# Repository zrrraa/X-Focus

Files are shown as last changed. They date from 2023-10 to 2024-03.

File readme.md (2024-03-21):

# X-Focus 智能桌面伴侣

一个可检测使用者学习和工作情况以及环境噪声的桌面伴侣，在APP内可查看监督报告。

<center class = 'img' >
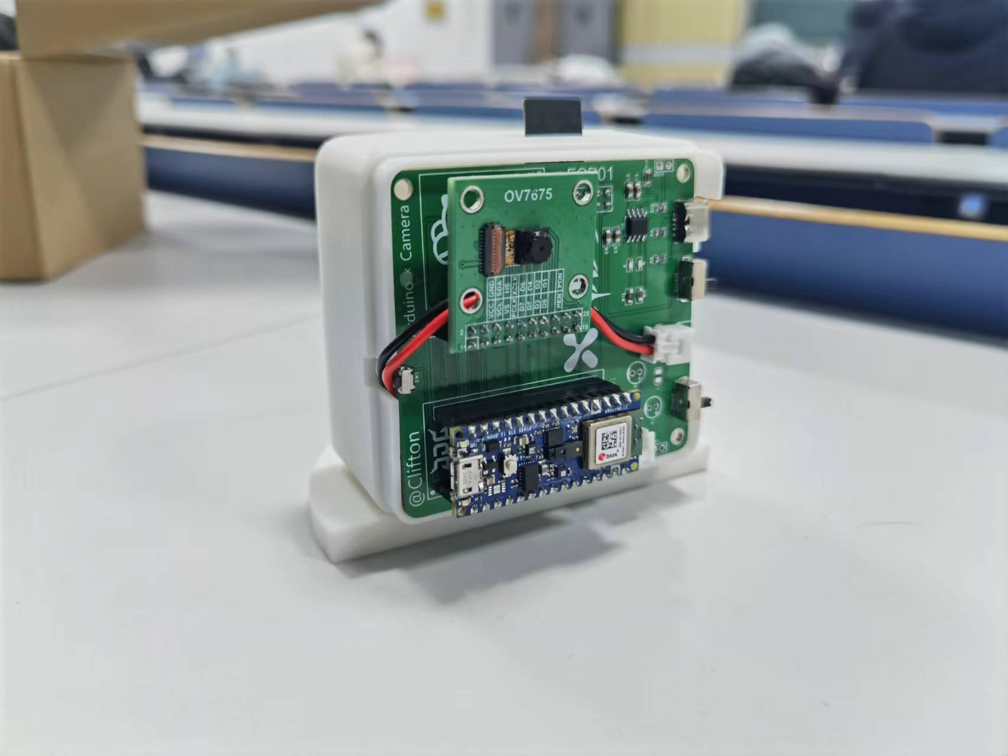
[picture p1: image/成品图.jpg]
X-Focus

</center>

随着媒体技术的发展和互联网时代的革命，洪流般的信息在推动时代进步的同时也无形中降低了人们的耐心阈值。当“专注”成为普遍关注的话题，如何检测专注度便成为了亟待解决的问题。

X-Focus诞生于这样的情境之下，旨在打造一款陪伴用户学习与工作的智能桌面伴侣，助力检验专注度。

## 技术路径

<center class = 'img' >
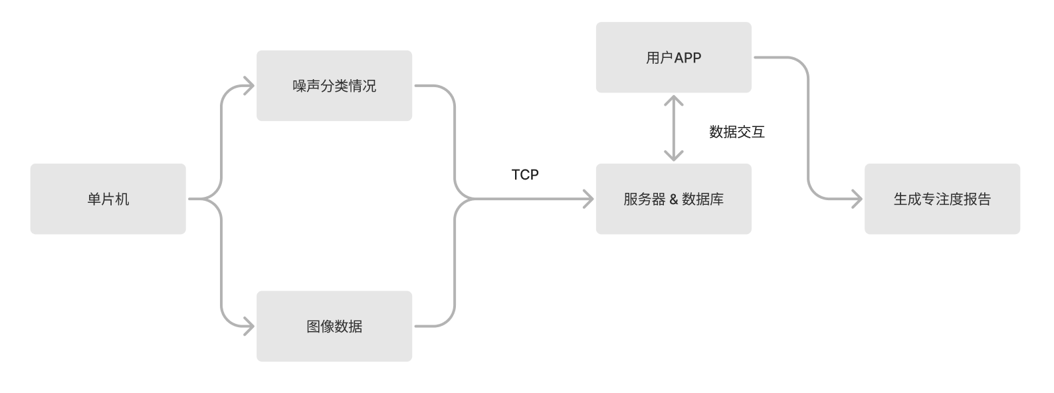
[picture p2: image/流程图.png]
流程图

</center>

硬件部分，X-Focus采用Arduino Nano 33 BLE作为主控，利用ov7675摄像头实时读取用户的工作状态，同时利用MP34DT05实时采集环境噪声。噪声经由存在单片机内部的预训练神经网络模型权重参数直接计算得分类结果，而图像数据则通过esp8266基于TCP发送给服务器，在服务器中通过SVM预测用户当前的工作状态。软件部分，我们基于PYQT5搭建了轻量级的上位机APP，协同后端SQLite数据库进行数据交互，每个用户都可注册自己的账号，查阅独属于自己的专注度报告，实现了一台设备的多人共享，助力X-Focus走进图书馆，办公室等公共场合。

## 功能演示

开机启动X-Focus

https://github.com/zrrraa/X-Focus/assets/105407119/f7af75d5-0d5c-4295-9356-713c125a4616

使用电脑状态检测

https://github.com/zrrraa/X-Focus/assets/105407119/e276f914-b43a-4757-9397-768390018e64

离开状态检测

https://github.com/zrrraa/X-Focus/assets/105407119/6a12a4db-4bc4-4c27-8759-1919a981f59a

读书状态以及使用手机状态检测

https://github.com/zrrraa/X-Focus/assets/105407119/01b09853-e76d-4802-b92e-d4feedbde9a1

用户在每一次学习或工作结束后都可在APP上查看状态报告，并与过去的报告进行对比，分析专注度。

<center class = 'img' >
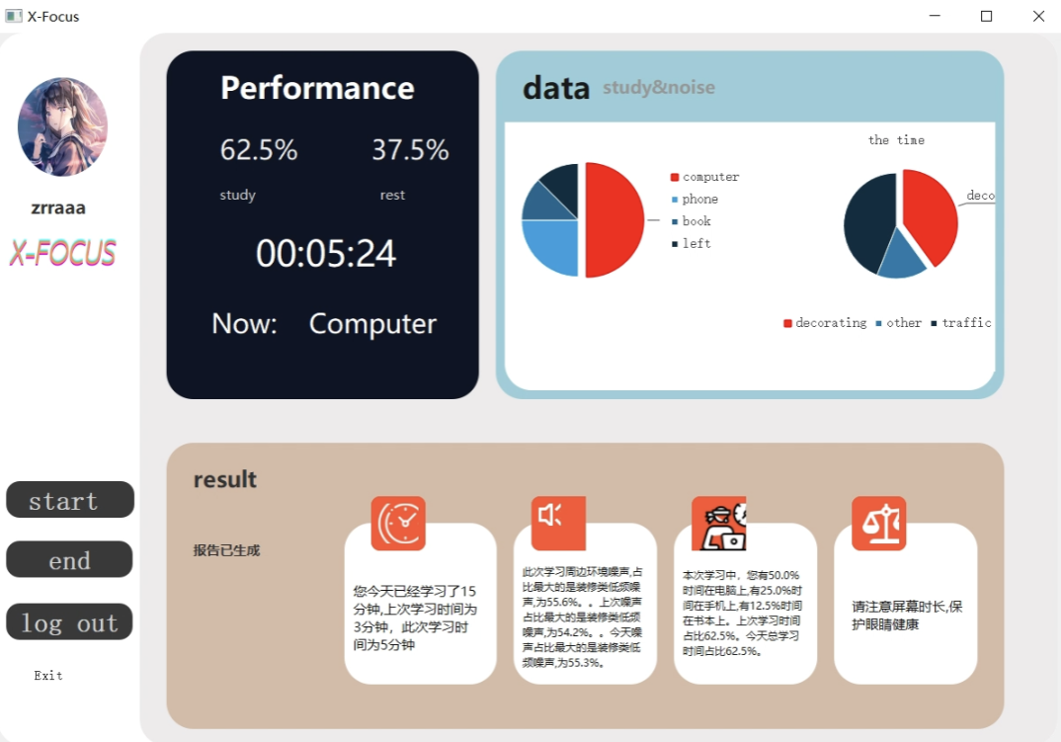
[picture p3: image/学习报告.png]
学习报告

</center>

## 参考资料

[SVMImageClassification](https://github.com/chestnut24/SVMImageClassification "基于SVM的简单机器学习分类，可以使用svm, knn, 朴素贝叶斯，决策树四种机器学习方法进行分类")

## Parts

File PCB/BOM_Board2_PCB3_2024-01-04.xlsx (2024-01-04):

No. | Quantity | Comment | Designator | Footprint | Value | Manufacturer Part | Manufacturer | Supplier Part | Supplier
1 | 3 | B-2100S02P-A110 | +5V,VBAT,VUSB | HDR-TH_2P-P2.54-V-M-1 |  | B-2100S02P-A110 | Ckmtw(灿科盟) | C124375 | LCSC
2 | 1 | 47uF | C1 | CAP-TH_BD5.0-P2.00-D0.8-FD | 47uF | 25YXF47MEFC5X11 | rubycon(红宝石) | C88724 | LCSC
3 | 1 | 100uF | C2 | CAP-TH_BD5.0-P2.00-D0.8-FD | 100uF | KM107M016D11RR0VH2FP0 | CX(承兴) | C43348 | LCSC
4 | 4 | 10u | C3,C4,C5,C6 | C0805 | 10u
5 | 2 | SK12D07VG3 | CHARGE,POWER | 拨动开关_侧 |  | SK12D07VG3 | SHOU HAN(首韩) | C431547 | LCSC
6 | 1 | XH-W-2A | CN1 | CONN-TH_2P-P2.50_DEALON_XH-W-2A |  | XH-W-2A | DEALON(德艺隆) | C5160919 | LCSC
7 | 1 | SS34 | D1 | SMA_L4.3-W2.6-LS5.2-RD |  | SS34 | MDD | C8678 | LCSC
8 | 1 | DS1023-2*4SF11 | ESP01 | HDR-TH_8P-P2.54-V-F-R2-C4-S2.54-1 |  | DS1023-2*4SF11 | CONNFLY | C92271 | LCSC
9 | 1 | LED_0805-G | G | LED_0603
10 | 2 | HDR-F_2.54_1x15P | H1,H2 | HDR-TH_15P-P2.54-V-F-1 |  |  |  | C124408
11 | 1 | HDR-F_2.54_2x10 | H3 | HDR-TH_20P-P2.54-V-R2-C10-S2.54 |  |  |  | C30867
12 | 1 | 47uH | L1 | L0805 | 47uH
13 | 1 | LED_0805-R | LED1 | LED_0603
14 | 1 | LED_0603-R | R | LED_0603
15 | 3 | 0R | R1,R3,R5 | R0805 | 0R
16 | 2 | 10K | R7,R12 | R0805 | 10K
17 | 2 | 6.6k | R8,R9 | R0805 | 6.6k
18 | 1 | 0.25R | R10 | R0805 | 0.25R
19 | 1 | 2K | R11 | R0805 | 2K
20 | 1 | 1.2K | R13 | R0805 | 1.2K
21 | 1 | TS24CA | SW1 | SW-SMD_TS24CA |  | TS24CA | SHOU HAN(首韩) | C393942 | LCSC
22 | 1 | QX2303L50T | U1 | SOT-23-3_L2.9-W1.6-P1.90-LS2.8-BR |  | QX2303L50T | 泉芯 | C219027 | LCSC
23 | 1 | TP4056-42-ESOP8 | U2 | ESOP-8_L4.9-W3.9-P1.27-LS6.0-BL-EP |  | TP4056-42-ESOP8 | TOPPOWER(南京拓微) | C16581 | LCSC
24 | 1 | YTC-TC6-268 | U3 | TYPE-C-SMD_YIYUAN_YTC-TC6-268 |  | YTC-TC6-268 | YIYUAN(怡远) | C5260484 | LCSC

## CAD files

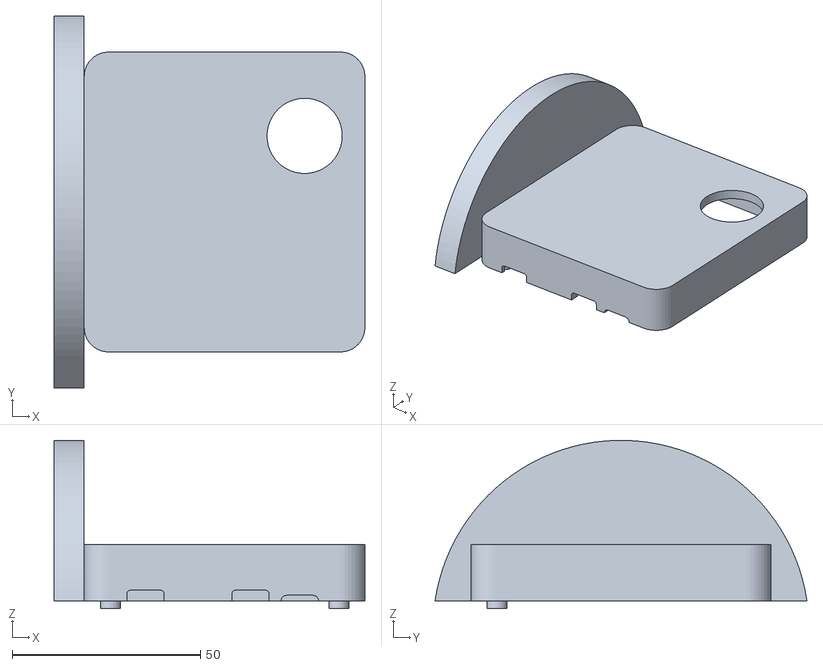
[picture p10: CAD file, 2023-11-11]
3Dmodel/顶部_v3.stl
82.7 x 98.9 x 44.7

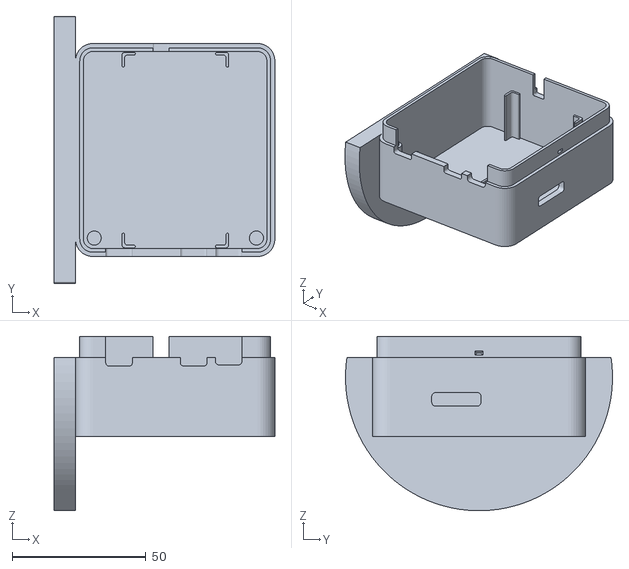
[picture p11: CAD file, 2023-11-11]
3Dmodel/底部_v3.stl
82.7 x 100.0 x 65.3

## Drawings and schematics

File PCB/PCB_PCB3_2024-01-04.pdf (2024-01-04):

@Clifton | Arduino | Camera

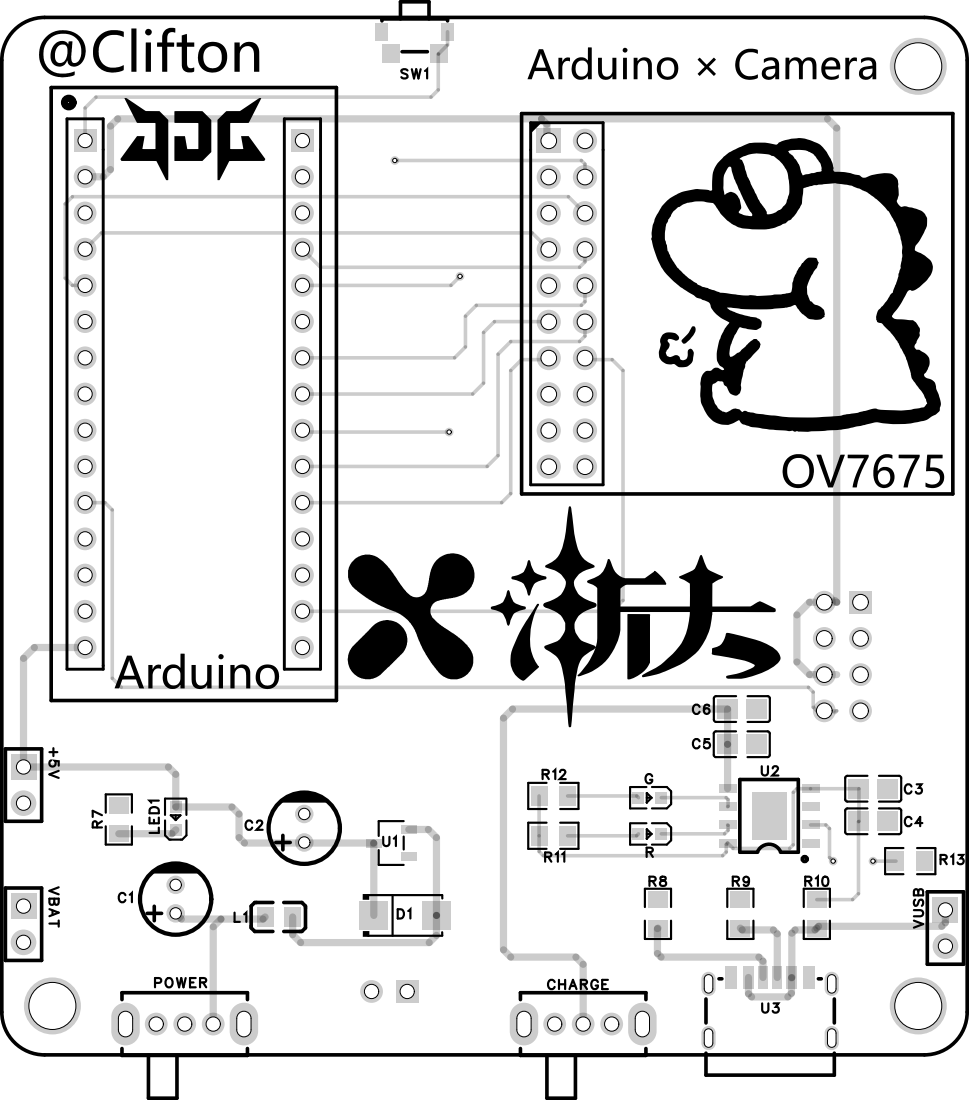
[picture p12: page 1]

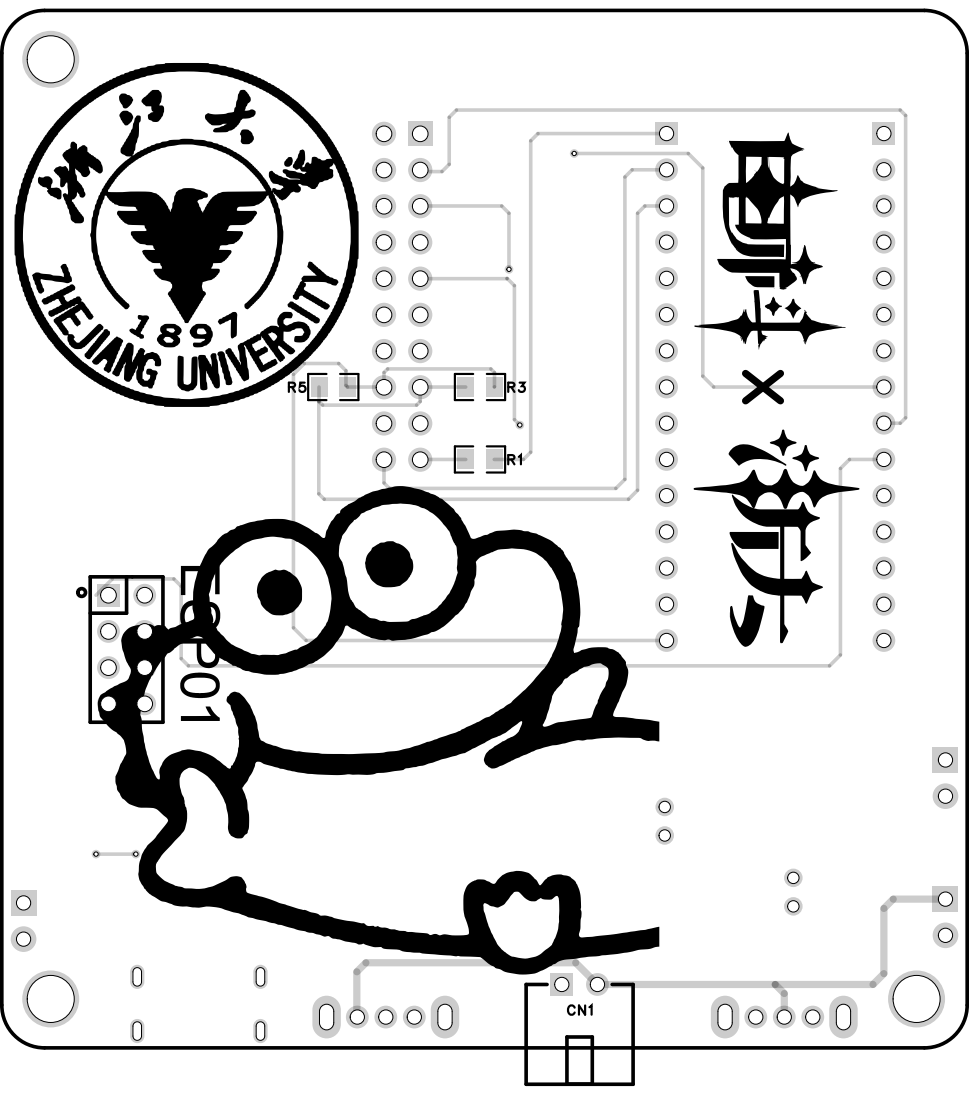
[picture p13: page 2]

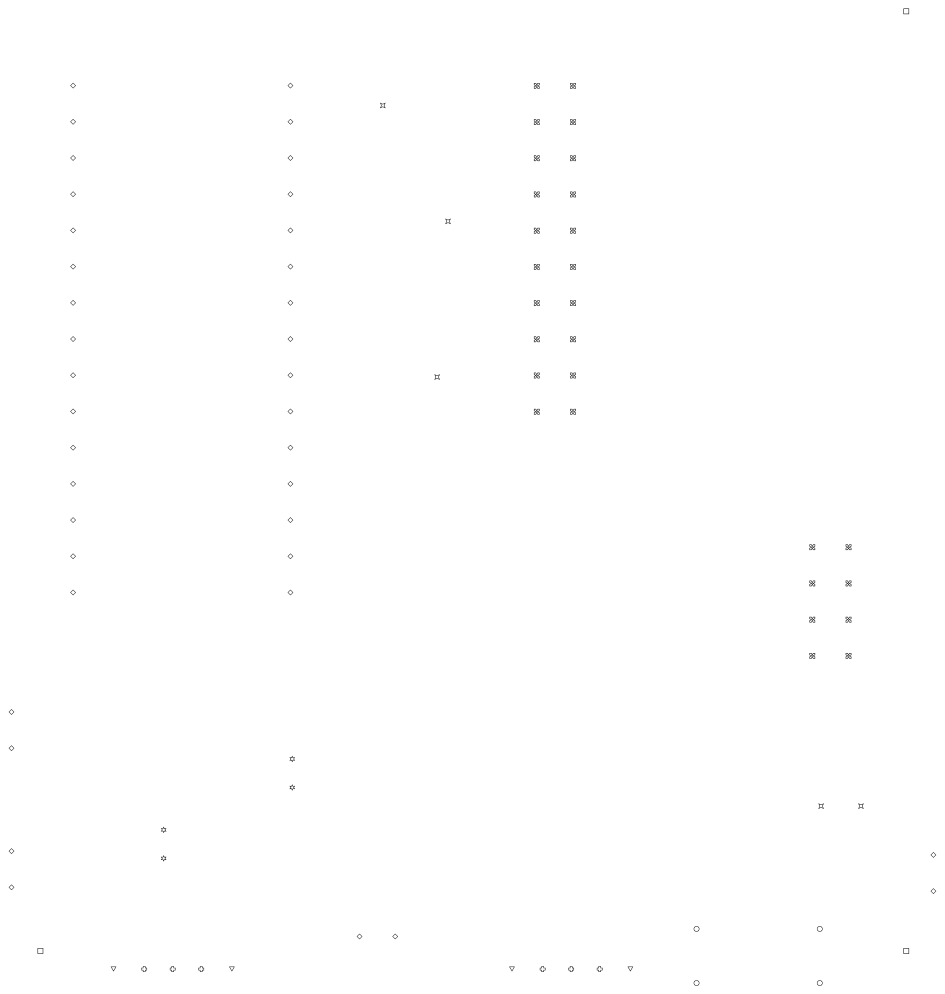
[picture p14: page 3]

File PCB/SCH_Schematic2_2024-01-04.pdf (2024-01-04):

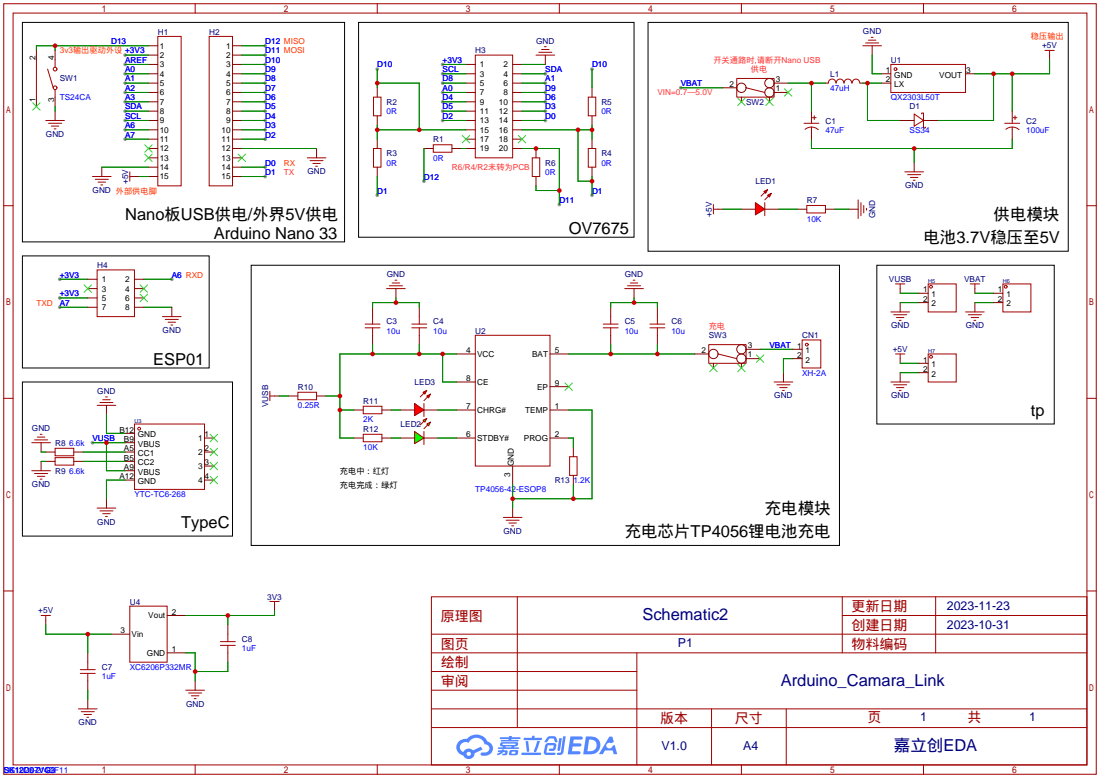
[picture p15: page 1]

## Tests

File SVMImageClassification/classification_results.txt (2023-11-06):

SVMImageClassification/test_photo/output_image_1.png:0
SVMImageClassification/test_photo/output_image_1.png:0
SVMImageClassification/test_photo/output_image_1.png:0
SVMImageClassification/test_photo/output_image_1.png:3
SVMImageClassification/test_photo/output_image_1.png:2
SVMImageClassification/test_photo/output_image_1.png:1
SVMImageClassification/test_photo/output_image_1.png:1
SVMImageClassification/test_photo/output_image_1.png:0
SVMImageClassification/test_photo/output_image_1.png:0
SVMImageClassification/test_photo/output_image_1.png:0
SVMImageClassification/test_photo/output_image_1.png:0
SVMImageClassification/test_photo/output_image_1.png:3
SVMImageClassification/test_photo/output_image_1.png:2
SVMImageClassification/test_photo/output_image_1.png:1
SVMImageClassification/test_photo/output_image_1.png:1
SVMImageClassification/test_photo/output_image_1.png:0
SVMImageClassification/test_photo/output_image_1.png:0
SVMImageClassification/test_photo/output_image_1.png:0
SVMImageClassification/test_photo/output_image_1.png:0
SVMImageClassification/test_photo/output_image_1.png:0
SVMImageClassification/test_photo/output_image_1.png:0
SVMImageClassification/test_photo/output_image_1.png:0
SVMImageClassification/test_photo/output_image_1.png:0
SVMImageClassification/test_photo/output_image_1.png:0
SVMImageClassification/test_photo/output_image_1.png:0
SVMImageClassification/test_photo/output_image_1.png:0

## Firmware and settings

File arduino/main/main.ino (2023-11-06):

#include <TinyMLShield.h>

#include <PDM.h>
#include <voice_detection_inferencing.h>

// wifi_upload, A6 for TX, A7 for RX
UART softSerial1(analogPinToPinName(6), analogPinToPinName(7), NC, NC);



// audio buffers, pointers and selectors
typedef struct {
  int16_t *buffer;
  uint8_t buf_ready;
  uint32_t buf_count;
  uint32_t n_samples;
} inference_t;

static inference_t inference;
static signed short sampleBuffer[2048];
static bool debug_nn = false; // Set this to true to see e.g. features generated from the raw signal

// camera flags
bool commandRecv = false; // flag used for indicating receipt of commands from serial port
bool liveFlag = false; // flag as true to live stream raw camera bytes, set as false to take single images on command
bool captureFlag = true;

// Image buffer
byte image[320 * 240 * 2]; // QVGA: 320x240 x 2 bytes per pixel (RGB565)
long long bytesPerFrame;

// setup
void setup() {
  Serial.begin(115200);
  while (!Serial);
  softSerial1.begin(115200);
  while (!softSerial1);

  // softSerial1.println("softSerial test");
  initializeShield();

  // initialize the microphone
  if (microphone_inference_start(EI_CLASSIFIER_RAW_SAMPLE_COUNT) == false) {
    ei_printf("ERR: Could not allocate audio buffer (size %d), this could be due to the window length of your model\r\n", EI_CLASSIFIER_RAW_SAMPLE_COUNT);
    return;
  }

  // initialize the OV7675 camera
  if (!Camera.begin(QVGA, RGB565, 1, OV7675)) {
    Serial.println("Failed to initialize camera");
    while (1);
  }
  bytesPerFrame = Camera.width() * Camera.height() * Camera.bytesPerPixel();

  if (microphone_inference_start(EI_CLASSIFIER_RAW_SAMPLE_COUNT) == false) {
        ei_printf("ERR: Could not allocate audio buffer (size %d), this could be due to the window length of your model\r\n", EI_CLASSIFIER_RAW_SAMPLE_COUNT);
        return;
    }

  //Serial.println("Welcome to the OV7675 test\n");
  //Serial.println("Available commands:\n");
  //Serial.println("single - take a single image and print out the hexadecimal for each pixel (default)");
  //Serial.println("live - the raw bytes of images will be streamed live over the serial port");
  //Serial.println("capture - when in single mode, initiates an image capture");


  //wifi init
  //Serial.begin(115200);
  // Serial1.begin(115200);
  // delay(3000);
  // Serial.println("wifi STA TCP test begin!");
  // Serial1.println("AT+CIPSTART=\"TCP\",\"192.168.124.7\",8080");
  // Serial.println("AT+CIPSTART=\"TCP\",\"192.168.124.7\",8080,WAITING...");
  // delay(5000);

  // Serial1.println("AT+CIPMODE=1");
  // Serial.println("AT+CIPMODE=1,WAITING...");
  // delay(2000);

  // Serial1.println("AT+CIPSEND");
  // Serial.println("AT+CIPSEND,WAITING...");
  // delay(2000);



  // initialize esp-01

  // softSerial1.listen();
  delay(3000);
  softSerial1.println("AT+CIPSTART=\"TCP\",\"192.168.124.7\",8090");
  delay(5000);

  softSerial1.println("AT+CIPMODE=1");
  delay(2000);

  softSerial1.println("AT+CIPSEND");
  delay(2000);
}

void loop() {
  int i = 0;
  String command;

  bool clicked = readShieldButton();
  if (clicked) {
    if (!liveFlag) {
      if (!captureFlag) {
        captureFlag = true;
      }
    }
  }

  

  // noise classfication and upload
  Serial.println("noise classfication and upload");
  delay(2000);

  bool m = microphone_inference_record();
  if (!m) {
    ei_printf("ERR: Failed to record audio...\n");
    return;
  }
  
  signal_t signal;
  signal.total_length = EI_CLASSIFIER_RAW_SAMPLE_COUNT;
  signal.get_data = &microphone_audio_signal_get_data;
  ei_impulse_result_t result = { 0 };

  EI_IMPULSE_ERROR r = run_classifier(&signal, &result, debug_nn);
  if (r != EI_IMPULSE_OK) {
    ei_printf("ERR: Failed to run classifier (%d)\n", r);
    return;
  }
  //  // print the predictions
  //  ei_printf("Predictions ");
  //  ei_printf("(DSP: %d ms., Classification: %d ms., Anomaly: %d ms.)",
  //            result.timing.dsp, result.timing.classification, result.timing.anomaly);
  //  ei_printf(": \n");
  for (size_t ix = 0; ix < EI_CLASSIFIER_LABEL_COUNT; ix++) {
    ei_printf("%s: %.5f\n", result.classification[ix].label, result.classification[ix].value);
  }
  for (size_t ix = 0; ix < EI_CLASSIFIER_LABEL_COUNT; ix++) {
    softSerial1.print(result.classification[ix].value);

    if (ix != EI_CLASSIFIER_LABEL_COUNT - 1) {
      softSerial1.print(", ");
    }
  }
  softSerial1.print("; ");// ";" to split noise and photo
#if EI_CLASSIFIER_HAS_ANOMALY == 1
  ei_printf("    anomaly score: %.3f\n", result.anomaly);
#endif

  // photo capture and upload
  Serial.println("photo capture and upload");
  if (captureFlag) {
    captureFlag = false;
    Camera.readFrame(image);
    //Serial.println("\nImage data will be printed out in 3 seconds...");
    delay(3000);
    //      for (int i = 0; i < bytesPerFrame - 1; i += 2) {
    //        Serial.print("0x");
    //        Serial.print(image[i+1], HEX);
    //        Serial.print(image[i], HEX);
    //        if (i != bytesPerFrame - 2) {
    //          Serial.print(", ");
    //        }
    //      }
    //      Serial.println();
    Serial.println("uploading photo...");

    //wifi upload
    for (int i = 0; i < bytesPerFrame - 1; i += 2) {
      softSerial1.print("0x");
      softSerial1.print(image[i + 1], HEX);
      softSerial1.print(image[i], HEX);
      if (i != bytesPerFrame - 2) {
        softSerial1.print(", ");
      }
    }
    // "\n" for once upload
    softSerial1.println();
    captureFlag = true;

    //time interval
    delay(5000);//20s一次

  }
}

// noise detection lib
/**
   @brief      PDM buffer full callback
               Get data and call audio thread callback
*/
static void pdm_data_ready_inference_callback(void)
{
  int bytesAvailable = PDM.available();

  // read into the sample buffer
  int bytesRead = PDM.read((char *)&sampleBuffer[0], bytesAvailable);

  if (inference.buf_ready == 0) {
    for (int i = 0; i < bytesRead >> 1; i++) {
      inference.buffer[inference.buf_count++] = sampleBuffer[i];

      if (inference.buf_count >= inference.n_samples) {
        inference.buf_count = 0;
        inference.buf_ready = 1;
        break;
      }
    }
  }
}

/**
   @brief      Init inferencing struct and setup/start PDM

   @param[in]  n_samples  The n samples

   @return     { description_of_the_return_value }
*/
static bool microphone_inference_start(uint32_t n_samples)
{
  inference.buffer = (int16_t *)malloc(n_samples * sizeof(int16_t));

  if (inference.buffer == NULL) {
    return false;
  }

  inference.buf_count  = 0;
  inference.n_samples  = n_samples;
  inference.buf_ready  = 0;

  // configure the data receive callback
  PDM.onReceive(&pdm_data_ready_inference_callback);

  PDM.setBufferSize(4096);

  // initialize PDM with:
  // - one channel (mono mode)
  // - a 16 kHz sample rate
  if (!PDM.begin(1, EI_CLASSIFIER_FREQUENCY)) {
    ei_printf("Failed to start PDM!");
    microphone_inference_end();

    return false;
  }

  // set the gain, defaults to 20
  PDM.setGain(127);

  return true;
}

/**
   @brief      Wait on new data

   @return     True when finished
*/
static bool microphone_inference_record(void)
{
  inference.buf_ready = 0;
  inference.buf_count = 0;

  while (inference.buf_ready == 0) {
    delay(10);
  }

  return true;
}

/**
   Get raw audio signal data
*/
static int microphone_audio_signal_get_data(size_t offset, size_t length, float *out_ptr)
{
  numpy::int16_to_float(&inference.buffer[offset], out_ptr, length);

  return 0;
}

/**
   @brief      Stop PDM and release buffers
*/
static void microphone_inference_end(void)
{
  PDM.end();
  free(inference.buffer);
}

#if !defined(EI_CLASSIFIER_SENSOR) || EI_CLASSIFIER_SENSOR != EI_CLASSIFIER_SENSOR_MICROPHONE
#error "Invalid model for current sensor."
#endif

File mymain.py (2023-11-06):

import sys
from PyQt5 import QtCore, QtGui, QtWidgets
from PyQt5.QtChart import QChart, QChartView, QPieSeries, QPieSlice

#导入串口模块
from dependencies.window_ui.main_ui import Ui_Form
import serial.tools.list_ports

#导入画图模块
import pyqtgraph as pg

#数字处理，取对数
from PyQt5.QtWidgets import *
from PyQt5.QtGui import *
from PyQt5.QtCore import *

#以下为主线程函数
from dependencies.window_ui.login_window import Ui_login
import time
from dependencies.window_ui.signup import Ui_signup
import sqlite3
import numpy as np
import random
import datetime
import socket
import struct
from matplotlib import pyplot as plt

import os
import cv2
from sklearn.model_selection import train_test_split
from sklearn.metrics import confusion_matrix, classification_report
from sklearn.svm import SVC
import matplotlib as mpl

zhanghao_now = ''
status_list = []

#本工程运用三个数据库，分别存储用户账号信息(user_index),用户登录信息（user_login),
# 用户学习信息（user_info）
#sql3 = sqlite3.connect("user_index.db")
#sql3.execute("create table users (id integer primary key,zhanghao varchar(10) UNIQUE,mima text NULL)")#建立表格

#sql3 = sqlite3.connect("user_login.db")
#sql3.execute("create table users_login (id integer primary key, zhanghao varchar(10) ,time text NULL)")#建立表格

#sql3 = sqlite3.connect("user_status_classfication.db")
#sql3.execute("create table users_status_classfication (id integer primary key AUTOINCREMENT, zhanghao varchar(10) ,totaltime integer,today varchar(10),computer integer, phone integer,read integer,left integer)")#建立表格

#sql3 = sqlite3.connect("user_audio_classfication.db")
#sql3.execute("create table users_audio_classfication (id integer primary key AUTOINCREMENT, zhanghao varchar(10) ,totaltime integer,today varchar(10),decorating real, noise real, whistling real)")#建立表格

#cur=sql3.cursor()
'''for t in[(1,'张三',0.33,0.66,0.999),(0,'李四',0.66,0.77,0.88)]:
 
  cur.execute("insert into users_audio_classfication (zhanghao,total,train,cough,other) values (?,?,?,?,?)", t)
  last_id = cur.lastrowid
  print(str(last_id))
  sql3.commit()'''
# 获取当前日期
#current_date = datetime.datetime.now().date()
#print( current_date)


class MysignupForm(QMainWindow, Ui_signup):

    def __init__(self):
        #这里需要重载一下Login_window，同时也包含了QtWidgets.QMainWindow的预加载项。

        super(MysignupForm, self).__init__()
        self.signup_ui = Ui_signup()
        self.signup_ui.setupUi(self)
        self.signup_ui.sql3 = sqlite3.connect(
            'dependencies/database/user_index.db')  #建立数据库/连接数据库
        self.signup_ui.sign_up_button.clicked.connect(
            self.signup_db)  #与数据库更新查询函数进行连接
        self.signup_ui.back_button.clicked.connect(
            self.back_up)  #与数据库更新查询函数进行连接

        self.setGeometry(250, 50, 1200, 800)
        self.signup_ui.palette = QPalette()
        #self.setWindowFlag(Qt.FramelessWindowHint)  #取消边框
        #self.setWindowFlags(Qt.WindowMinMaxButtonsHint)
        #self.signup_ui.palette.setBrush(QPalette.backgroundRole(), QBrush(QPixmap("images/login_1.png")))
        self.signup_ui.palette.setBrush(
            MysignupForm.backgroundRole(self),
            QBrush(
                QPixmap("dependencies/images/signup.jpg").scaled(
                    MysignupForm.size(self), QtCore.Qt.IgnoreAspectRatio,
                    QtCore.Qt.SmoothTransformation)))
        self.signup_ui.label_5.setPixmap(
            QPixmap('dependencies/images/x_focus_black').scaled(
                self.signup_ui.label_5.size(), QtCore.Qt.IgnoreAspectRatio,
                QtCore.Qt.SmoothTransformation))  #后面两个命令用于抗锯齿
        self.signup_ui.op1 = QtWidgets.QGraphicsOpacityEffect()
        self.signup_ui.op2 = QtWidgets.QGraphicsOpacityEffect()
        self.signup_ui.op3 = QtWidgets.QGraphicsOpacityEffect()
        # 设置透明度的值，0.0到1.0，最小值0是透明，1是不透明
        self.signup_ui.op1.setOpacity(0.8)
        self.signup_ui.op2.setOpacity(0.9)
        self.signup_ui.op3.setOpacity(0.9)

        self.signup_ui.label_4.setGraphicsEffect(self.signup_ui.op1)
        self.signup_ui.back_button.setGraphicsEffect(self.signup_ui.op2)
        self.signup_ui.sign_up_button.setGraphicsEffect(self.signup_ui.op3)
        self.signup_ui.label_4.setStyleSheet(
            '''QLabel{background:#FFFFFF;border-radius:20px;}QLabel{;font-size:30px;color:rgb(200,200,200);}'''
        )

        self.signup_ui.back_button.setStyleSheet(
            '''QPushButton{background:#111111;border-radius:5px;}QPushButton:hover{background:#333333;}QPushButton{;font-size:30px;color:rgb(207,181,59);font-family : '微软雅黑';}'''
        )
        self.signup_ui.sign_up_button.setStyleSheet(
            '''QPushButton{background:#111111;border-radius:5px;}QPushButton:hover{background:#333333;}QPushButton{;font-size:30px;color:rgb(207,181,59);font-family : '微软雅黑';}'''
        )
        #self.signup_ui.backup.setStyleSheet('''QPushButton{background:#222222;border-radius:5px;}QPushButton:hover{background:grey;}''')
        self.signup_ui.thelogo.setPixmap(
            QPixmap('dependencies/images/logo.png').scaled(
                self.signup_ui.thelogo.size()))
        self.signup_ui.label_5.setStyleSheet(
            '''QLabel{font-size:30px;color:rgb(33,33,33);font-family : '微软雅黑';}'''
        )
        self.signup_ui.label.setStyleSheet(
            '''QLabel{font-size:20px;color:rgb(33,33,33);font-family : '微软雅黑';}'''
        )
        self.signup_ui.label_2.setStyleSheet(
            '''QLabel{font-size:20px;color:rgb(33,33,33);font-family : '微软雅黑';}'''
        )
        self.signup_ui.label_3.setStyleSheet(
            '''QLabel{font-size:20px;color:rgb(33,33,33);font-family : '微软雅黑';}'''
        )

        self.signup_ui.zhanghao.setStyleSheet(
            '''QLabel{font-size:15px;color:rgb(33,33,33);font-family : '微软雅黑';}'''
        )
        self.signup_ui.mima.setStyleSheet(
            '''QLabel{font-size:15px;color:rgb(33,33,33);font-family : '微软雅黑';}'''
        )
        self.signup_ui.querenmima.setStyleSheet(
            '''QLabel{font-size:15px;color:rgb(33,33,33);font-family : '微软雅黑';}'''
        )

        self.setPalette(self.signup_ui.palette)

    def back_up(self):
        mysignup.close()
        mylogin.show()
        mylogin.data_clean()  #可以直接调用函数进行操作

    def signup_db(self):
        self.signup_ui.cursor = self.signup_ui.sql3.cursor()
        self.signup_ui.results = self.signup_ui.cursor.execute(
            "SELECT * FROM users")
        self.signup_ui.users = self.signup_ui.results.fetchall()  # 结果转成元组
        self.signup_ui.flag = 0  #标志位

        for user in self.signup_ui.users:  #获取表格内数据
            if (user[1] == self.signup_ui.zhanghao.text()):
                self.signup_ui.flag = 1

        if (self.signup_ui.zhanghao.text()
                == '') or ((self.signup_ui.mima.text() == '')):
            result2 = QMessageBox.critical(
                self, "错误", "<font color=\"#000000\">请输入完整</font>",
                QMessageBox.Ok | QMessageBox.Cancel, QMessageBox.Cancel)  #有空着的
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

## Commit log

2023-10-18 上传目前进度
2023-10-18 修改了readme.md的内容
2023-10-18 wifi_upload开发
2023-10-18 添加了wifi_upload.py
2023-10-18 添加了web_test
2023-10-18 10.18web test 第一次提交失败
2023-10-19 web_test，app_test通过
2023-10-19 修改了readme
2023-10-24 同步开发进度，10.25，硬件和软件独立调试成功，尚未连接
2023-10-27 修改串口上传分辨率为320*240
2023-10-28 QVGA格式图像传输成功，增添了传输丢包保护代码
2023-10-30 添加噪声分类代码
2023-10-30 添加了前端对接说明文档
2023-10-30 添加了main.py与前端说明文档
2023-11-02 增加了噪声分类代码和3D模型文件
    [Edge底部.stl, Edge顶部.stl]
2023-11-03 上传了v2模型，同步了调试进度
    [Edge底部 v2.stl, Edge顶部 v2.stl]
2023-11-05 2023.11.5前端对接
    [Edge底部 v2.1.stl, Edge底部 v2.2.stl, Edge顶部 v2.1.stl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]
2023-11-05 更新了md文件
2023-11-06 11.6答辩修正
2023-11-06 评价与后续改进
2023-11-11 上传了新的3Dmodel
    [底部_v3.stl, 顶部_v3.stl]
2023-11-11 上传了功能演示视频
2024-01-04 重新理了一下文件
    [BOM_Board2_PCB3_2024-01-04.xlsx]
2024-01-04 更新了readme
